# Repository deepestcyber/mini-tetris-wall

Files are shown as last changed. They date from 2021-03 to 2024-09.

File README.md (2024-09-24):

# Mini Tetris Board

Mainly the PCB design (WIP)

Example:

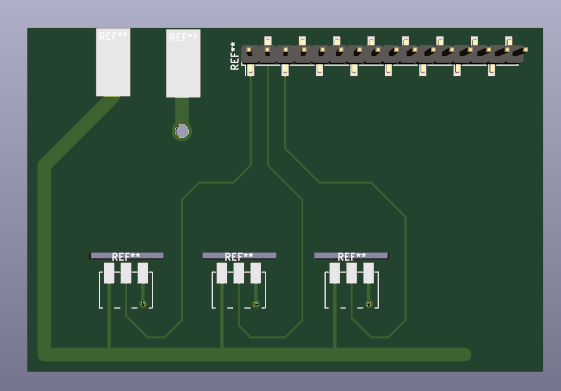
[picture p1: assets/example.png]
pcb image


# Planing and ideas
Wir sollten den von KiCAD gedachten Weg nehmen, und mit den Schematics anfangen. Damit haben wir dann auch zumindest eine
Plausibilitätsprüfung für's Netz.

Idee für die Platine: vergrößern auf die Außenmaße des unteren Rahmens (der Kasten für die Elektronik), Bohrlöcher mit vorsehen.
Dann können wir es direkt mit dem Rest verschrauben. Aufpassen, dass im Rand kein Metall in den Layern ist, um elektrisch von außen
getrennt zu bleiben! Daten für Größe könnte man vermutlich aus den Laserdaten nehmen. Nachteil: Platine ist nur befestigt, wenn
der Rahmen zu ist.

# TODOs:
* ~~Footprint für SMD-Shild Arduino Mega~~
* ~~Footprint für SMD-Shild Raspi~~
* Stiftleisten fuer alle Switches
* Stiftleisten fuer Status-LED strips
* Power Button
* USB-Port vom RasPi nach aussen
* USB-C power input?
    * USB-C power inlet with negotiation
    * https://www.komputer.de/zen/index.php?main_page=product_info&products_id=635&zenid=bo7534ob5tfdgg7ghbn8ceoa73
* Lueftung fuer StepDown converter einplanen?
    * Power budget fuer LED strips ist 5V * 24 * 16 * 60mA (~= 115W)
* ~~Dicke! Powerlines~~
* ~~SPI und ready line~~
* logic level shifter 5V->3V3 für Leitungen Arduino->Raspi
* DeepCyber Logo auf Platine!
* Name, revision, url des repos auf platine

# Löten?
Ich höre, JLCPCB macht einseitige Bestückung für Bauteile, die sie haben. Da wir nur Stift- und Buchsenleisten haben, könnte das was werden.

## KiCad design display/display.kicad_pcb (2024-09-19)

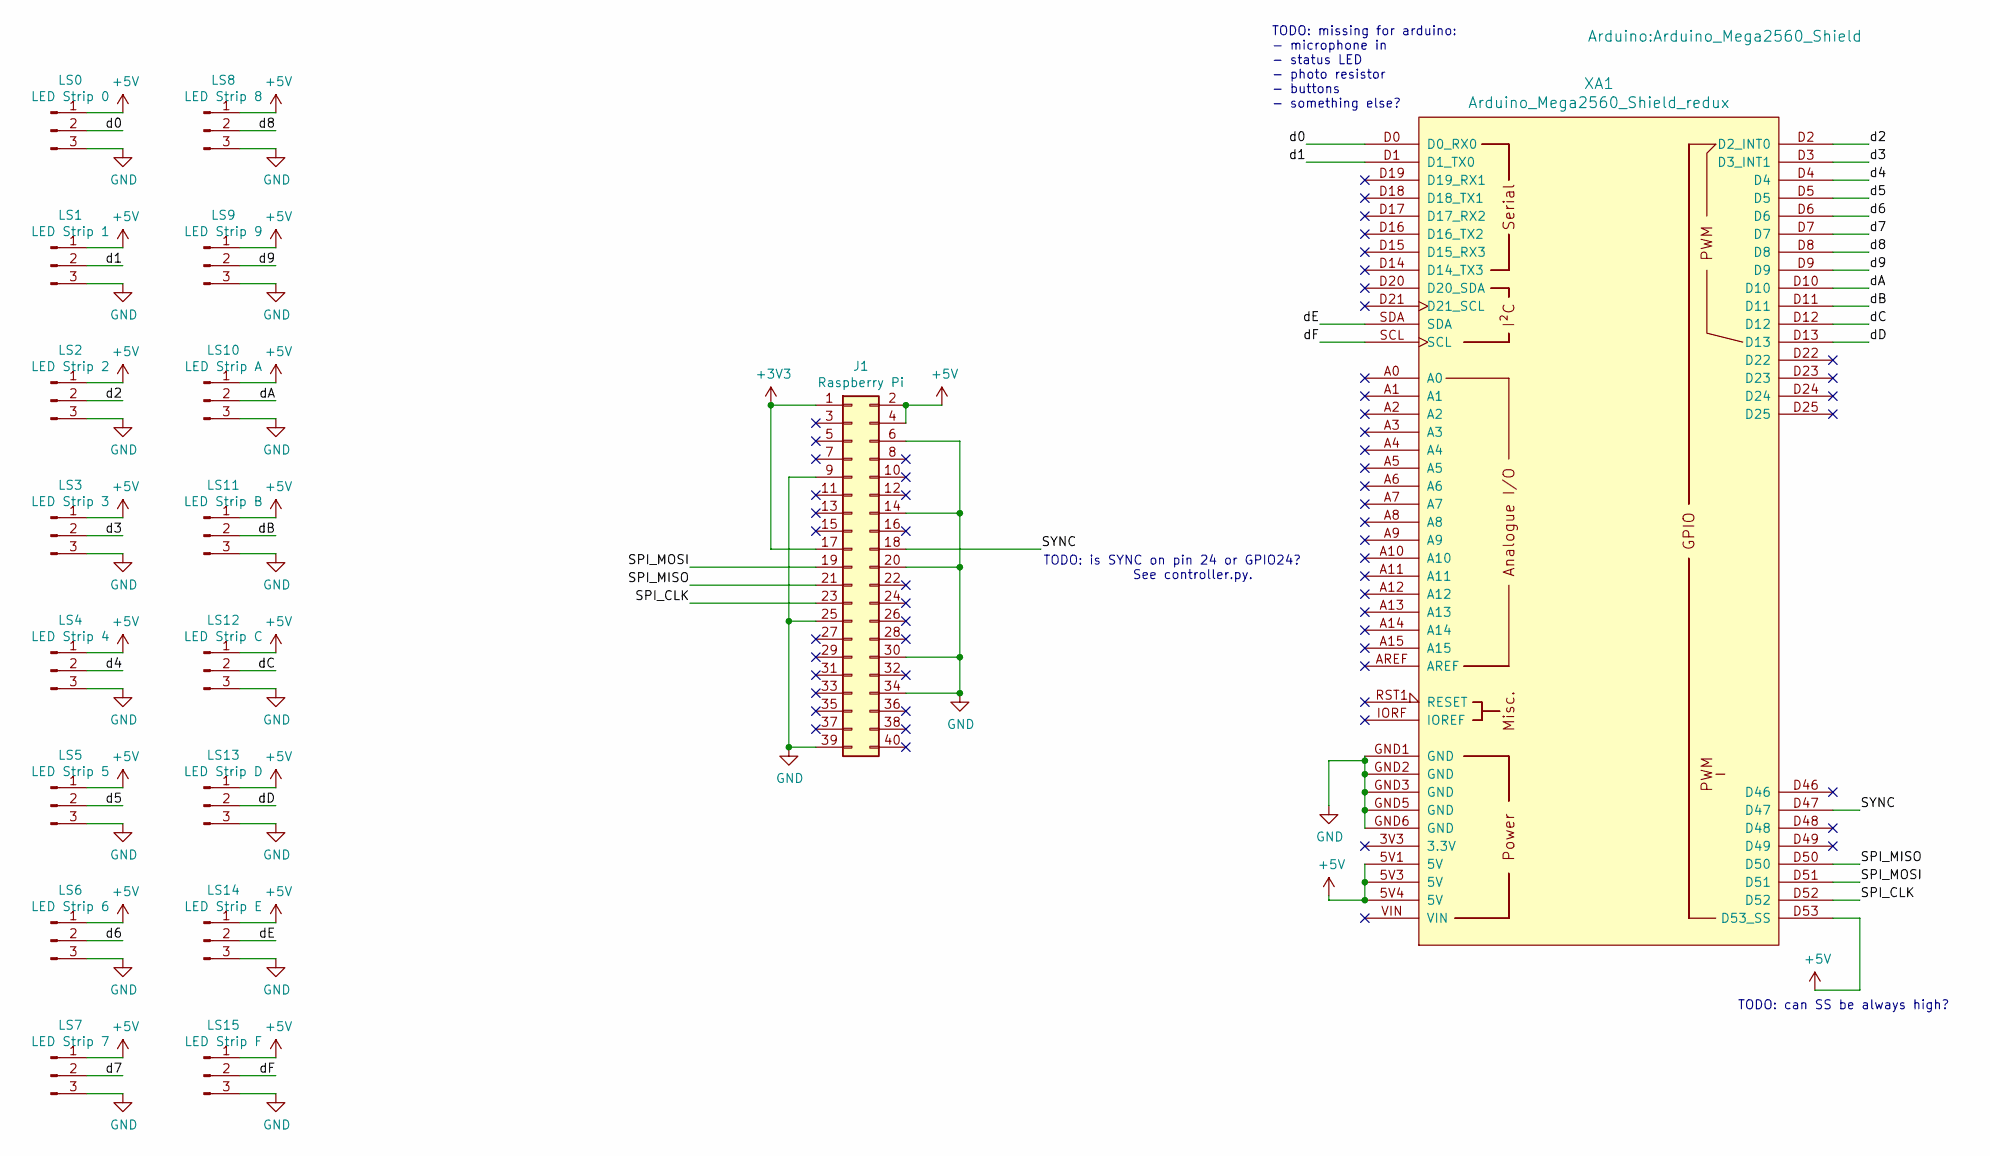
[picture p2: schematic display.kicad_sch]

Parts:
J1: Raspberry Pi; raspberrypi_2_3
LS0: LED Strip 0; strip_connector_hole
LS1: LED Strip 1; strip_connector_hole
LS2: LED Strip 2; strip_connector_hole
LS3: LED Strip 3; strip_connector_hole
LS4: LED Strip 4; strip_connector_hole
LS5: LED Strip 5; strip_connector_hole
LS6: LED Strip 6; strip_connector_hole
LS7: LED Strip 7; strip_connector_hole
LS8: LED Strip 8; strip_connector_hole
LS9: LED Strip 9; strip_connector_hole
LS10: LED Strip A; strip_connector_hole
LS11: LED Strip B; strip_connector_hole
LS12: LED Strip C; strip_connector_hole
LS13: LED Strip D; strip_connector_hole
LS14: LED Strip E; strip_connector_hole
LS15: LED Strip F; strip_connector_hole
XA1: Arduino_Mega2560_Shield_redux; Arduino_Mega2560_Shield

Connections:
+3V3: J1.1, J1.17
+5V: J1.2, J1.4, LS0.1, LS1.1, LS2.1, LS3.1, LS4.1, LS5.1, LS6.1, LS7.1, LS8.1, LS9.1, LS10.1, LS11.1, LS12.1, LS13.1, LS14.1, LS15.1, XA1.5V1 (5V), XA1.5V3 (5V), XA1.5V4 (5V), XA1.D53 (D53_SS); also elsewhere on the board
/SPI_CLK: J1.23, XA1.D52
/SPI_MISO: J1.21, XA1.D50
/SPI_MOSI: J1.19, XA1.D51
/SYNC: J1.18, XA1.D47
/d0: LS0.2, XA1.D0 (D0_RX0)
/d1: LS1.2, XA1.D1 (D1_TX0)
/d2: LS2.2, XA1.D2 (D2_INT0)
/d3: LS3.2, XA1.D3 (D3_INT1)
/d4: LS4.2, XA1.D4
/d5: LS5.2, XA1.D5
/d6: LS6.2, XA1.D6
/d7: LS7.2, XA1.D7
/d8: LS8.2, XA1.D8
/d9: LS9.2, XA1.D9
/dA: LS10.2, XA1.D10
/dB: LS11.2, XA1.D11
/dC: LS12.2, XA1.D12
/dD: LS13.2, XA1.D13
/dE: LS14.2, XA1.SDA
/dF: LS15.2, XA1.SCL
GND: J1.6, J1.9, J1.14, J1.20, J1.25, J1.30, J1.34, J1.39, LS0.3, LS1.3, LS2.3, LS3.3, LS4.3, LS5.3, LS6.3, LS7.3, LS8.3, LS9.3, LS10.3, LS11.3, LS12.3, LS13.3, LS14.3, LS15.3, XA1.GND1 (GND), XA1.GND2 (GND), XA1.GND3 (GND), XA1.GND5 (GND), XA1.GND6 (GND)

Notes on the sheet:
TODO: missing for arduino: - microphone in - status LED - photo resistor - buttons - something else?
TODO: can SS be always high?
TODO: is SYNC on pin 24 or GPIO24? See controller.py.

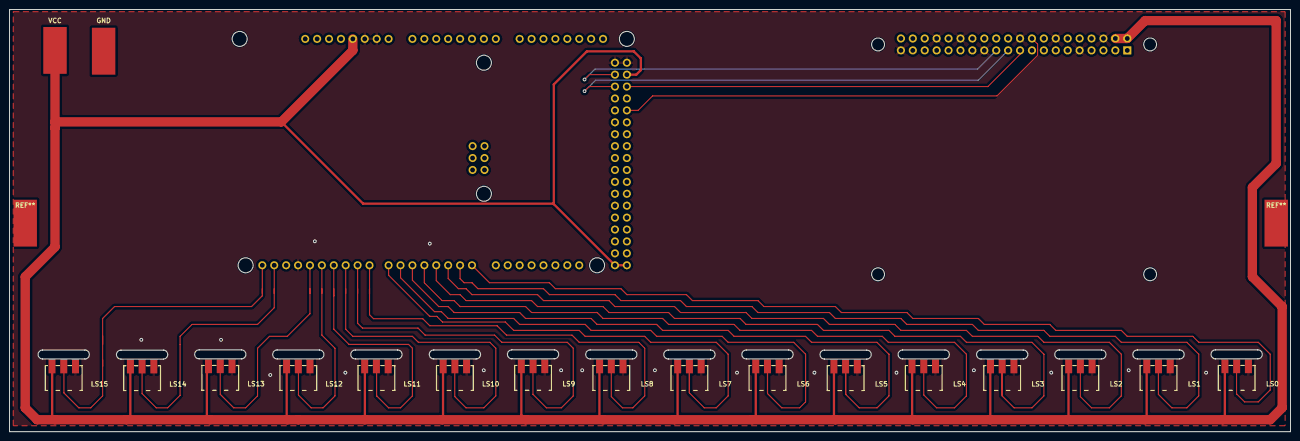
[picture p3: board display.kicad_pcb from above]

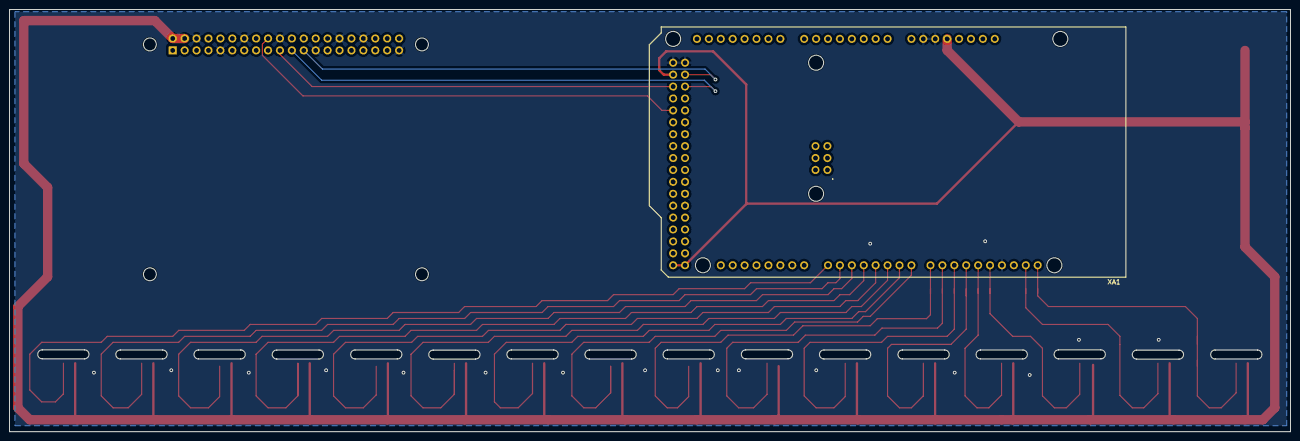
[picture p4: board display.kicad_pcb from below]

Board: 2 copper layers, 273.1 x 90.0 mm, 20 parts (2 on the bottom side), 23 nets.

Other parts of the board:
GND: GND; SolderWirePad_1x01_SMD_5x10mm
VCC: VCC; SolderWirePad_1x01_SMD_5x10mm

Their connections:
+5V: VCC.1; also elsewhere on the board

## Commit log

2021-03-02 Initial :3
    [display.kicad_pcb, display.sch, strip_connector.sch]
2021-03-03 Connect all signals
    [display.kicad_pcb]
2021-03-03 New board dimensions
    6mm spacing to left/right
    9cm absolute height
    [display.kicad_pcb]
2021-03-03 For easier layouting prototype as svg
2021-03-04 PoC arduino pins
    [display.kicad_pcb]
2021-03-11 WIP peer
    [display.kicad_pcb, display.sch]
2024-07-30 Revive project
    - Hopefully correct footprint for Arduino Mega
    - Replaced all connectors with the one from the schematic footprint
    - Replaced pi header with the one from the schematic
    - Added infill (front & back) for easy grounding
    We can now proceed to wire everything up, mainly the connection between
    Arduino and Pi.
    [display.kicad_pcb, display.kicad_sch]
2024-07-30 Update to kicad 8
    [display.kicad_pcb, display.kicad_sch]
2024-07-30 Add SPI and SYNC pins
    [display.kicad_pcb, display.kicad_sch]
2024-09-19 Some progress with the peer
    [display.kicad_pcb]
